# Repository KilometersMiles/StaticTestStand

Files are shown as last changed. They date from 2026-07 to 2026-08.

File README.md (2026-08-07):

# Static Test Stand
A test stand to measure a force-time curve for small rocket motors. This is designed for collecting data on small A-class motors. 

## Onshape Link
The files are available for download here on the Github or you can use the Onshape document.
https://cad.onshape.com/documents/dc1ea5a17a6875eff156904f/w/99ff55d2b2f774a85729f015/e/69d40390ca9ec5910e336e51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

## Bill of Materials

| Name | Quantity | Price Per Unit | Total Price | Link |  | Grand Total: | 80.57 |
| --- | --- | --- | --- | --- | --- | --- | --- |
| Load Cell/HX711 Module | 1 | 6.79 | 6.79 | https://www.amazon.com/NOYITO-10kg-20kg-HX711-Combo/dp/B07BGXXHSW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 |  |  |  |
| goBilda U Channel 10 Hole | 3 | 13.99 | 41.97 | https://www.gobilda.com/1120-series-u-channel-10-hole-264mm-length/ |  |  |  |
| goBilda Quad Block | 2 | 6.99 | 13.98 | https://www.gobilda.com/1201-series-quad-block-pattern-mount-43-2/ |  |  |  |
| Raspberry PI Pico | 1 | 7.84 | 7.84 | https://www.amazon.com/Raspberry-Pi-Pico/dp/B09KVB8LVR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 |  |  |  |
| Breadboard &amp; Jumper Wires Kit | 1 | 9.99 | 9.99 | https://www.amazon.com/BOJACK-Values-Solderless-Breadboard-Flexible/dp/B08Y59P6D1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 |  |  |  |
| Motor Mount | 1 | Printed |  |  |  |  |  |
| Blast Shield | 1 | Printed |  |  |  |  |  |
| goBilda to Load Cell Adapter | 1 | Printed |  |  |  |  |  |

## Build Instructions
1. Obtain all materials
  - 3D Print Adapter Square, Blast Shield and Motor Mount.
  - 3 10 Hole GoBilda U-Channel and 2 GoBilda quad blocks.
  - 16 M4 Screws and Bolts
  - Raspberry PI Pico
  - HX711 and 5kg Load Cell
  - USB Micro Battery Pack
2. Wiring
Follow this diagram. Made in Cirkit Designer. Link: https://app.cirkitdesigner.com/project/235e4502-1041-476a-81f1-36d9f1a2d234

3. Build
  - Use 2 M4 screws to mount the quad blocks to the end of two U-Channels
   
  - Attach these to the third U-Channel using two more M4 Screws on each side.
   
  - Screw in the Adapter Square to the third U-channel using the 4 corner holes and 4 M4 Screws. Make sure the center of the square is over a hole
    
  - Screw in the Load Cell to the Adapter Square
   
  - Screw in the Motor Mount to the Load Cell
    
  - Place electronic system in corner of U-Channel
   
   - Secure the sheild with 4 M4 Screws
     

## Test Instructions
Download the code from the code folder and upload it using Thonny.
To start recording data for 30 seconds, plug in the battery. The recording starts automatically. 
Use Thonny to then view/export the generated CSV file holding the data.

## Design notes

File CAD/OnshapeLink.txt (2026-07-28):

This was designed in Onshape. For the most up-to-date design, check this link:
https://cad.onshape.com/documents/dc1ea5a17a6875eff156904f/w/99ff55d2b2f774a85729f015/e/69d40390ca9ec5910e336e51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

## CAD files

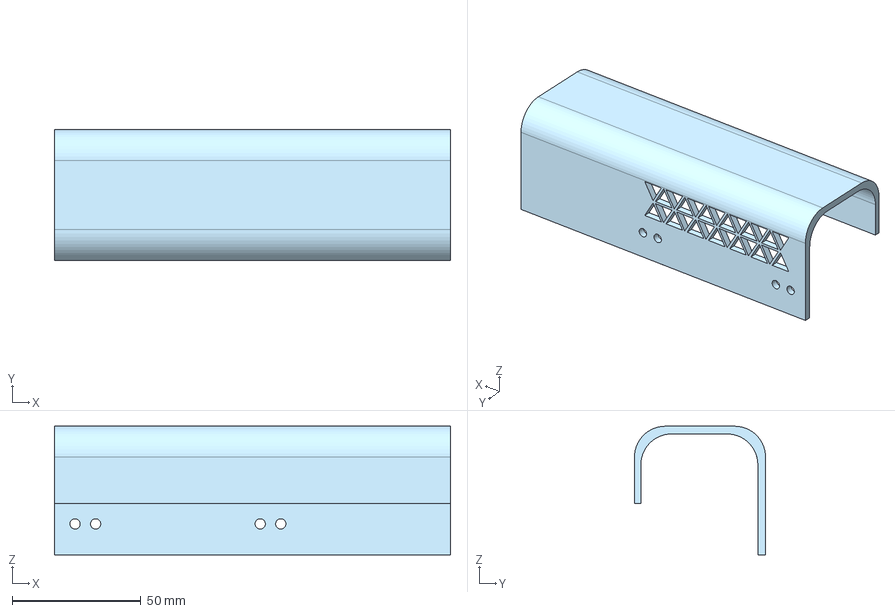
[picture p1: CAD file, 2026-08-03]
CAD/Parts/BlastShield.step
154.0 x 51.0 x 50.0 mm

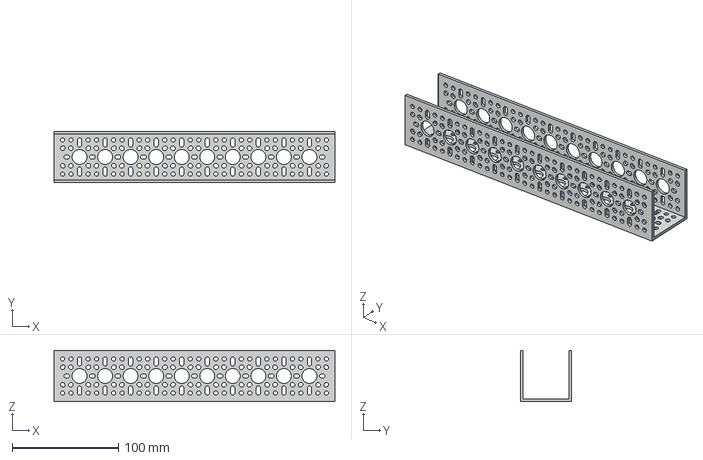
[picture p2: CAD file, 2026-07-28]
CAD/Parts/1120 Series U-Channel (10 Hole, 264mm Length) 1120-0010-0264 (2).step
264.0 x 48.0 x 48.0 mm

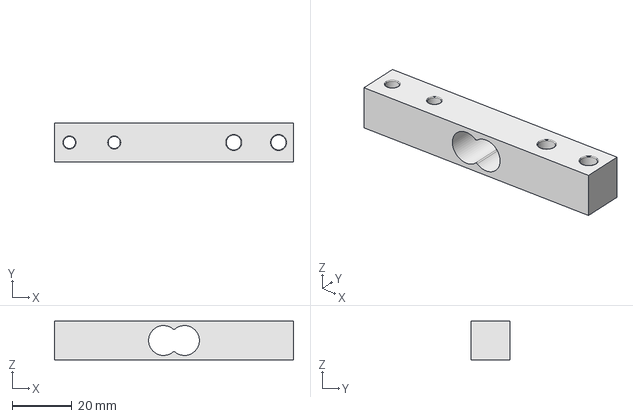
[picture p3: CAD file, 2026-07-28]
CAD/Parts/Loadcell_5kg v7.step
80.0 x 13.0 x 13.0 mm

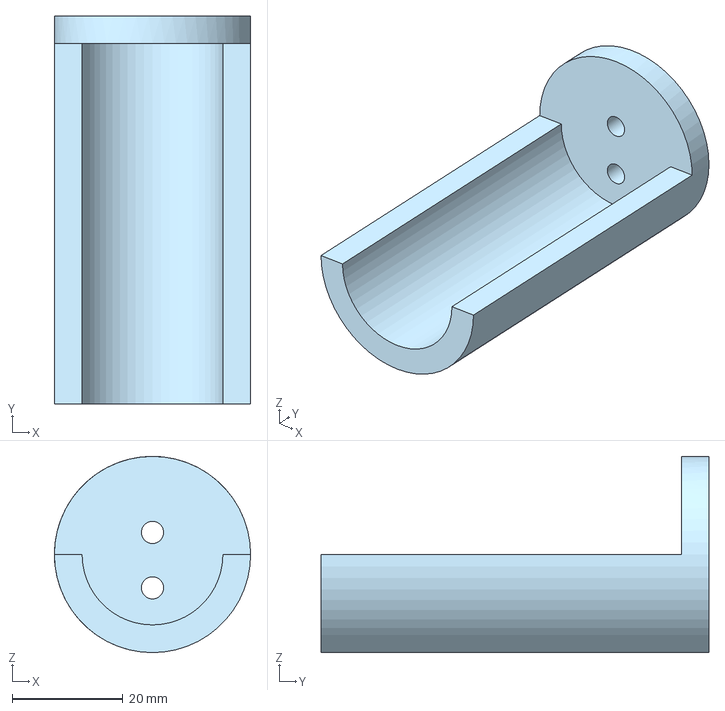
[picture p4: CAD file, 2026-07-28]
CAD/Parts/MotorMount.step
35.4 x 70.0 x 35.4 mm

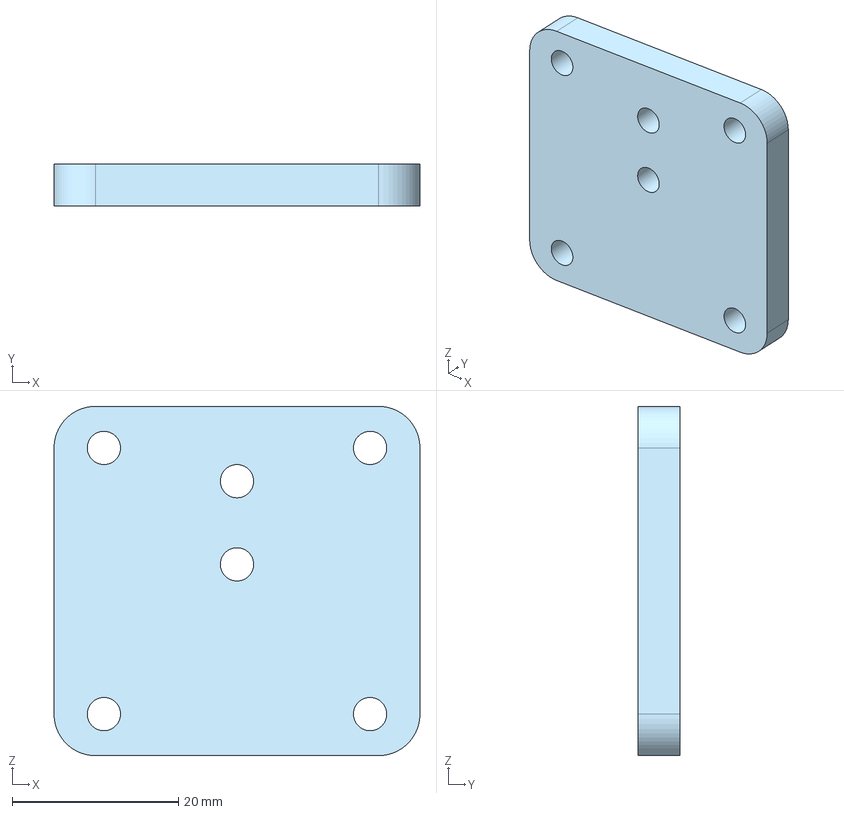
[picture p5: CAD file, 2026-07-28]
CAD/Parts/CellToGobildaAdapter.step
44.0 x 5.00 x 42.0 mm

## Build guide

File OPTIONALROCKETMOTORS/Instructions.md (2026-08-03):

I logged the hours for building the test motors so here's the info for that. There is no CAD or files for this. This is NOT an official motor recipe and is VERY experimental. Make at your own risk.

## Materials
- PVC Pipe
- Ammonium Perchorate Powder
- Aluminum Powder
- Silicone
- Kitty Litter

## Instructions
- Cut the PVC Pipe into a 4 inch section.
- Grind up a half cup of Kitty Litter in an old blender or with a mortar and pestle. The essential ingredient is the Bentonite Clay which can be very strong.
- Put some kitty litter powder into the bottom of the pvc pipe and compress it with a ramrod and mallet until you have a 1cm layer that is incompressible.
- Separately, prepare the rocket motor fuel. Mix the ammonium perchlorate (50% by weight), aluminum (25%) and silicone (25%).
- Carefully put the fuel into the motor casing, being VERY CAREFUL not to leave any air bubbles. Make an 1/8 in core down the middle (easily done with a pencil)
- Fill the rest of the motor with kitty litter and compress it with the ramrod and mallet.
- Drill an eighth inch hole in the clay as the nozzle. Make sure to clear all clay from the core.

## Launch instructions
- Use the ESTES model rocket starters to light it. Make sure to have at least a 15ft radius around it in case of catastrophic rapid unscheduled disassembly.

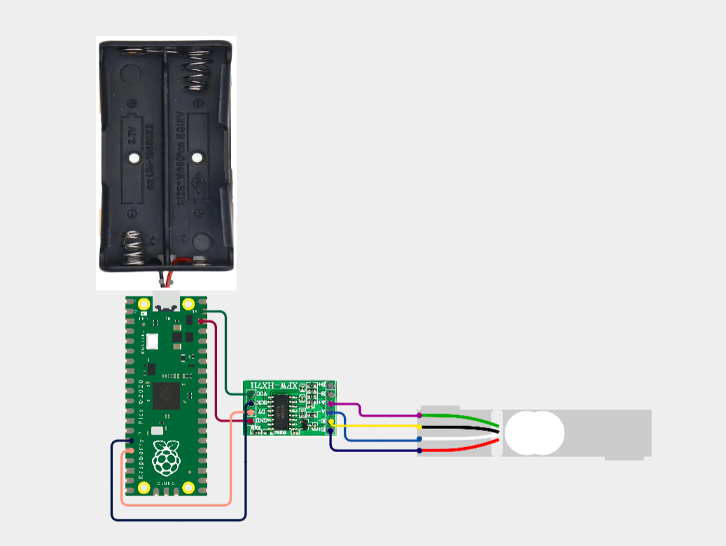
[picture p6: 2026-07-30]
WiringDiagram.png

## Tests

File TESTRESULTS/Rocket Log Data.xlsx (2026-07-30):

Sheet: testdata1
timestamp_us | timestamp seconds | raw_reading | reading
117473942 | 0 | -0.0058837532 | -0.0058837532
117565515 | 0.091573 | -0.13934814 | -0.13934814
117655720 | 0.181778 | -0.06784935 | -0.06784935
117746678 | 0.272736 | -0.06308277 | -0.06308277
117837631 | 0.363689 | -0.017800216 | -0.017800216
117928574 | 0.454632 | -0.0035004606 | -0.0035004606
118019534 | 0.545592 | 0.022715756 | 0.022715756
118110463 | 0.636521 | 0.020332464 | 0.020332464
118201406 | 0.727464 | -0.09406557 | -0.09406557
118292367 | 0.818425 | -0.08214911 | -0.08214911
118383296 | 0.909354 | -0.027333384 | -0.027333384
118474271 | 1.000329 | -0.04163314 | -0.04163314
118565227 | 1.091285 | 0.025099048 | 0.025099048
118656175 | 1.182233 | -0.017800216 | -0.017800216
118747114 | 1.273172 | -0.12981496 | -0.12981496
118838053 | 1.364111 | -0.11074862 | -0.11074862
118929006 | 1.455064 | -0.06308277 | -0.06308277
119019954 | 1.546012 | 0.02748234 | 0.02748234
119110898 | 1.636956 | -0.01303363 | -0.01303363
119201854 | 1.727912 | -0.13219824 | -0.13219824
119292867 | 1.818925 | -0.105982032 | -0.105982032
119383860 | 1.909918 | -0.15364788 | -0.15364788
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

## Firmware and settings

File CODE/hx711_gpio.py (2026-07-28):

# MIT License

# Copyright (c) 2019 

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
from machine import enable_irq, disable_irq, idle, Pin
import time

class HX711:
    def __init__(self, clock, data, gain=128):
        self.clock = clock
        self.data = data
        self.clock.value(False)

        self.GAIN = 0
        self.OFFSET = 0
        self.SCALE = 1

        self.time_constant = 0.25
        self.filtered = 0

        # determine the number of attempts to find the trigger pulse
        start = time.ticks_us()
        for _ in range(3):
            temp = self.data()
        spent = time.ticks_diff(time.ticks_us(), start)
        self.__wait_loop = 3_000_000 // spent

        self.set_gain(gain);

    def __call__(self):
        return self.read()

    def set_gain(self, gain):
        if gain is 128:
            self.GAIN = 1
        elif gain is 64:
            self.GAIN = 3
        elif gain is 32:
            self.GAIN = 2

        self.read()
        self.filtered = self.read()

    def conversion_done_cb(self, data):
        self.conversion_done = True
        data.irq(handler=None)

    def read(self):
        if hasattr(self.data, "irq"):
            self.conversion_done = False
            self.data.irq(trigger=Pin.IRQ_FALLING, handler=self.conversion_done_cb)
            # wait for the device being ready
            for _ in range(500):
                if self.conversion_done == True:
                    break
                time.sleep_ms(1)
            else:
                self.data.irq(handler=None)
                raise OSError("Sensor does not respond")
        else:
            # wait polling for the trigger pulse
            for _ in range(self.__wait_loop):
                if self.data():
                    break
            else:
                raise OSError("No trigger pulse found")
            for _ in range(5000):
                if not self.data():
                    break
                time.sleep_us(100)
            else:
                raise OSError("Sensor does not respond")

        # shift in data, and gain & channel info
        result = 0
        for j in range(24 + self.GAIN):
            state = disable_irq()
            self.clock(True)
            self.clock(False)
            enable_irq(state)
            result = (result << 1) | self.data()

        # shift back the extra bits
        result >>= self.GAIN

        # check sign
        if result > 0x7fffff:
            result -= 0x1000000

        return result - self.OFFSET

    def read_average(self, times=3):
        sum = 0
        for i in range(times):
            sum += self.read()
        return sum / times

    def read_lowpass(self):
        self.filtered += self.time_constant * (self.read() - self.filtered)
        return self.filtered

    def get_value(self):
        return self.read_lowpass() - self.OFFSET

    def get_units(self):
        return self.get_value() / self.SCALE

    def tare(self, times=15):
        self.set_offset(self.read_average(times))

    def set_scale(self, scale):
        self.SCALE = scale

    def set_offset(self, offset):
        self.OFFSET = offset

    def set_time_constant(self, time_constant = None):
        if time_constant is None:
            return self.time_constant
        elif 0 < time_constant < 1.0:
            self.time_constant = time_constant

    def power_down(self):
        self.clock.value(False)
        self.clock.value(True)

    def power_up(self):
        self.clock.value(False)

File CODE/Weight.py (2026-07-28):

from hx711_gpio import HX711
from machine import Pin
import time
import random

data_pin = Pin(19, Pin.IN, pull=Pin.PULL_DOWN)
clock_pin = Pin(18, Pin.OUT)

RUN_DURATION_SEC = 30
FLUSH_INTERVAL_COUNT = 500 # save every 500 samples so that all data doesn't get lost in case of catastrophic failure but also doesn't impact loop times as much.

hx711 = HX711(clock_pin, data_pin)

hx711.tare()

unique_id = time.ticks_us() # avoids duplicate  filenames
filename = f"log_{unique_id}.csv"
print(f"Creating data file: {filename}")

with open(filename, "w") as f:
    f.write("timestamp_us,raw_reading\n")

file = open(filename, "a")

timestamps = [0] * FLUSH_INTERVAL_COUNT
readings = [0] * FLUSH_INTERVAL_COUNT

start_time_ms = time.ticks_ms()
end_time_ms = start_time_ms + (RUN_DURATION_SEC * 1000)

sample_count = 0
total_samples_saved = 0
buffer_index = 0

print("log start")

try:
    while(time.ticks_ms() < end_time_ms):
        raw_wt = hx711.read()
        scale_factor = (97/40700) * (9.81/1000) #gets grams then converts to newtons
        
        weight = raw_wt * scale_factor
        # time.ticks_us() avoids heavy memory allocation overhead
        timestamps[buffer_index] = time.ticks_us()
        readings[buffer_index] = weight
        
        #print data
        print(f"{weight:.1f} Newtons", end="     \r")
        
        buffer_index += 1
        sample_count += 1
        
        if buffer_index >= FLUSH_INTERVAL_COUNT:
            lines = "".join(
                f"{time.ticks_diff(timestamps[i], start_time_us) / 1000000.0:.6f},{readings[i]}\n" 
                for i in range(FLUSH_INTERVAL_COUNT)
            )
            file.write(lines)
            file.flush() 
            
            total_samples_saved += FLUSH_INTERVAL_COUNT
            buffer_index = 0
    if buffer_index > 0:
        lines = "".join(f"{timestamps[i]},{readings[i]}\n" for i in range(buffer_index))
        file.write(lines)
        total_samples_saved += buffer_index

finally:
    file.close()
    print("Log done.")
    print(f"Total samples recorded: {total_samples_saved}")
    print(f"Average sample rate: {round(total_samples_saved / RUN_DURATION_SEC, 2)} Hz")

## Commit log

2026-07-28 Create Assemblies
2026-07-30 Fix spelling and update materials in README
2026-07-30 Add BOM
    [Test Stand BOM.csv]
2026-07-30 Rename BOM
    [BOM.csv]
2026-08-03 Add new blast shield
    [BlastShield.step]
2026-08-03 Update Instructions.md with safety and build details
    Added detailed instructions and safety warnings for building experimental rocket motors.
2026-08-07 Add BOM to readme
